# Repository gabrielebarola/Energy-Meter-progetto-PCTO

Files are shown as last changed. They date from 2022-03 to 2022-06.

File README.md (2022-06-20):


<!-- PROJECT LOGO -->
<br />
<div align="center">
  <a href="https://github.com/gabrielebarola/Energy-Meter-progetto-PCTO/">
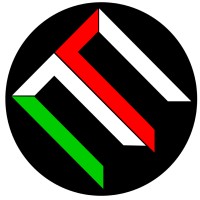
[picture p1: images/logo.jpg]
    
  </a>

<h3 align="center">Energy meter</h3>

  <p align="center">
    Progetto per il percorso di PCTO 2021/2022
  </p>
</div>

<!-- ABOUT THE PROJECT -->
## Il progetto

<div align="center">
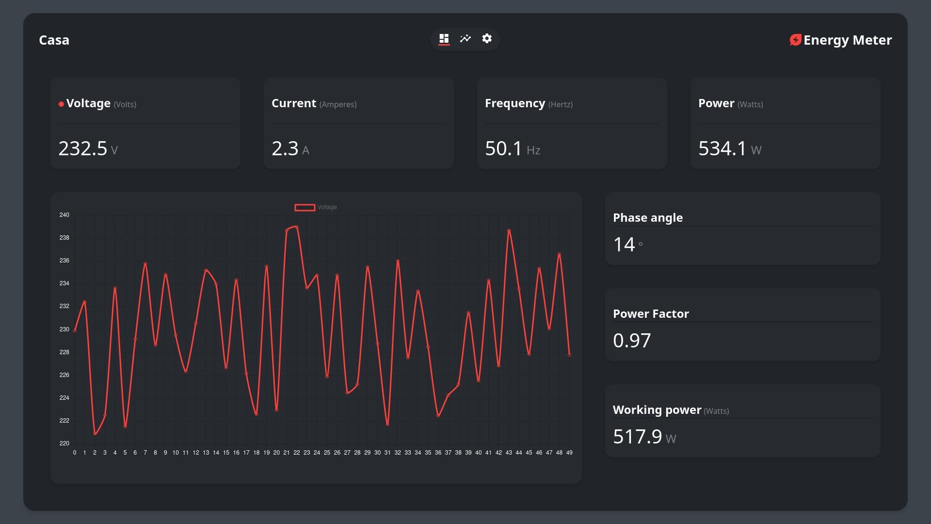
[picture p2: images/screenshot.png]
Dashboard
  
</div>

Cercando di collegare l'attività del PCTO con le tematiche trattate in educazione civica durante l'anno, ho deciso di sviluppare un sistema in grado di monitorare i parametri necessari per mostrare all'utente in modo semplice lo stato dell'impianto elettrico della propria abitazione e lo storico dei consumi, con l'obiettivo di incentivare un utilizzo più consapevole dell'energia elettrica.

Il progetto unisce in unico pacchetto tutte le funzionalità di seguito riportate e analizzate nello specifico successivamente.

* MISURA DELLE PRINCIPALI GRANDEZZE DI UN IMPIANTO ELETTRICO
* CALCOLO DELLA POTENZA E DEL FATTORE DI POTENZA
* VISUALIZZAZIONE DEI DATI IN TEMPO REALE
* GRAFICI INTERATTIVI

## Altre tecnologie e software utilizzati

* [MicroPython](https://micropython.org/)
* [Kicad](https://www.kicad.org/)
* [VSCode](https://code.visualstudio.com/)
* [MicroWebSrv2](https://github.com/jczic/MicroWebSrv2)
* [Charts.js](https://github.com/chartjs/Chart.js)

## Presentazione per l'esame di stato

<div>
  <a href="https://docs.google.com/presentation/d/1edAisyT30yDkEmbcdj5mdHnbcW9ENNGRGbsqXM53MuE/edit?usp=sharing">
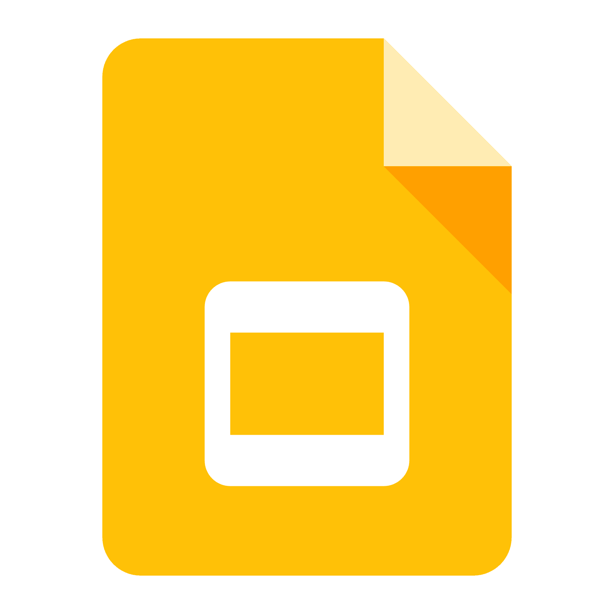
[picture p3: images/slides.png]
Clicca per vedere la presentazione
    
  </a>
  Premere sul logo per vedere la presentazione
</div>

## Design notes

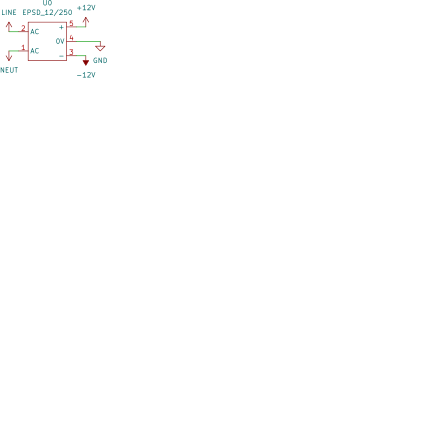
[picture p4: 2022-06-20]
kicad/tensione/al.png

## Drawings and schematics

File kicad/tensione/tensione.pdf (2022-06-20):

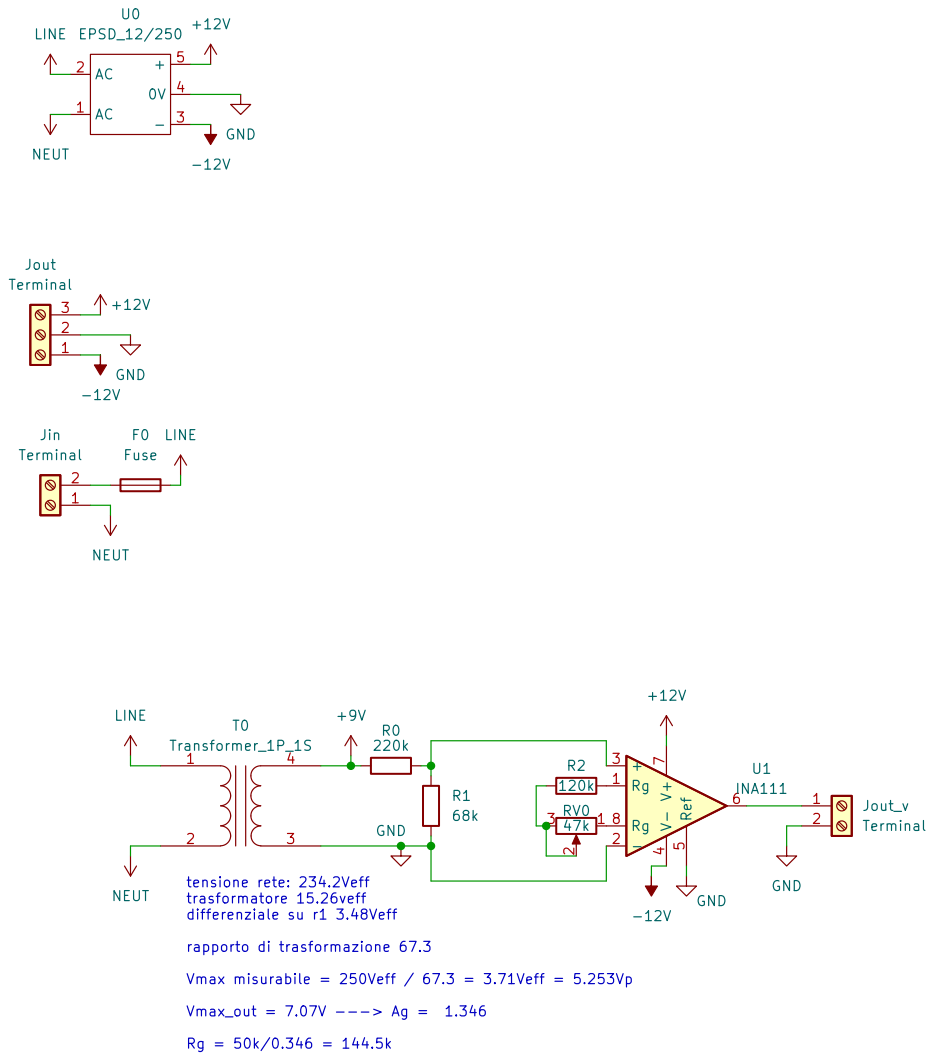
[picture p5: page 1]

tensione rete: 234.2Veff
trasformatore 15.26veff differenziale su r1 3.48Veff rapporto di trasformazione 67.3

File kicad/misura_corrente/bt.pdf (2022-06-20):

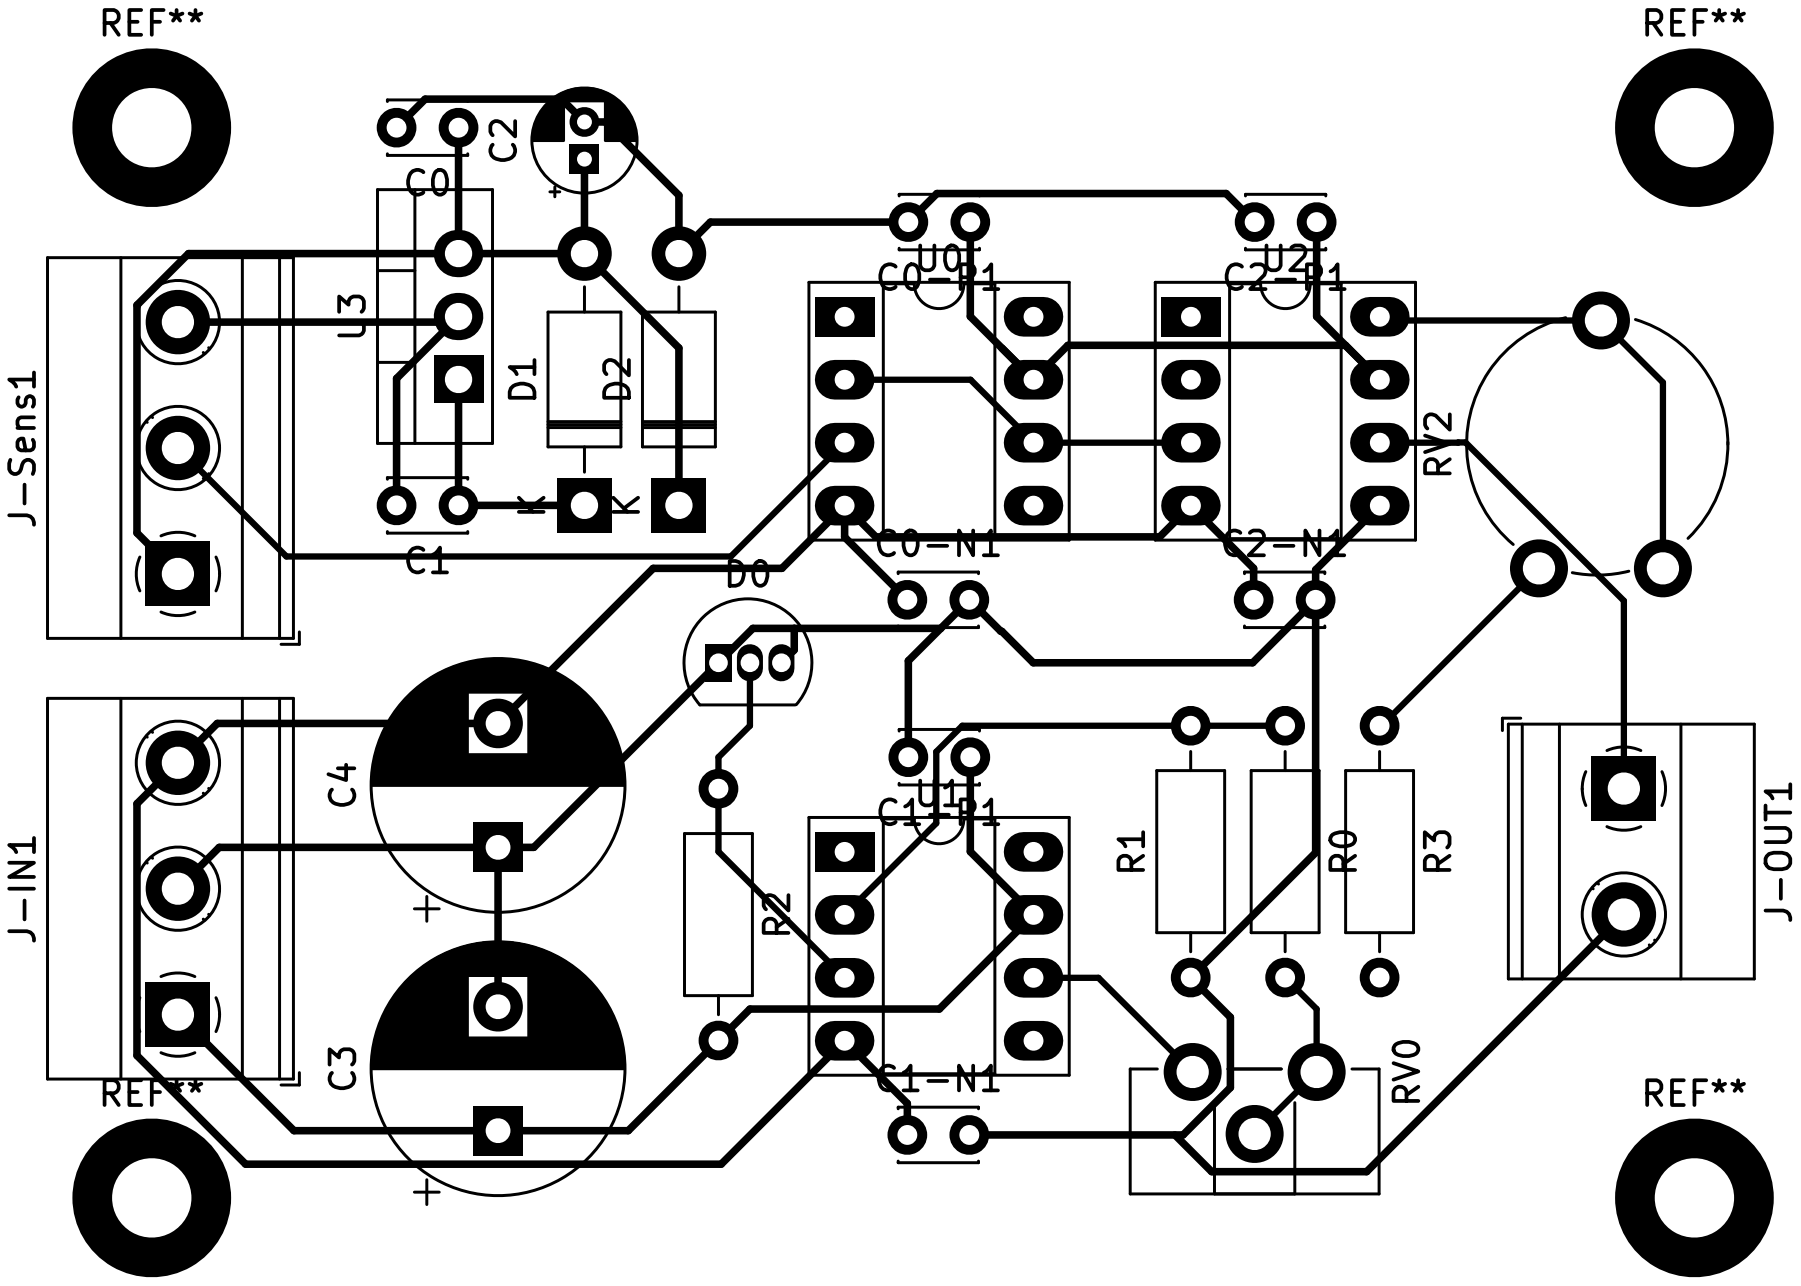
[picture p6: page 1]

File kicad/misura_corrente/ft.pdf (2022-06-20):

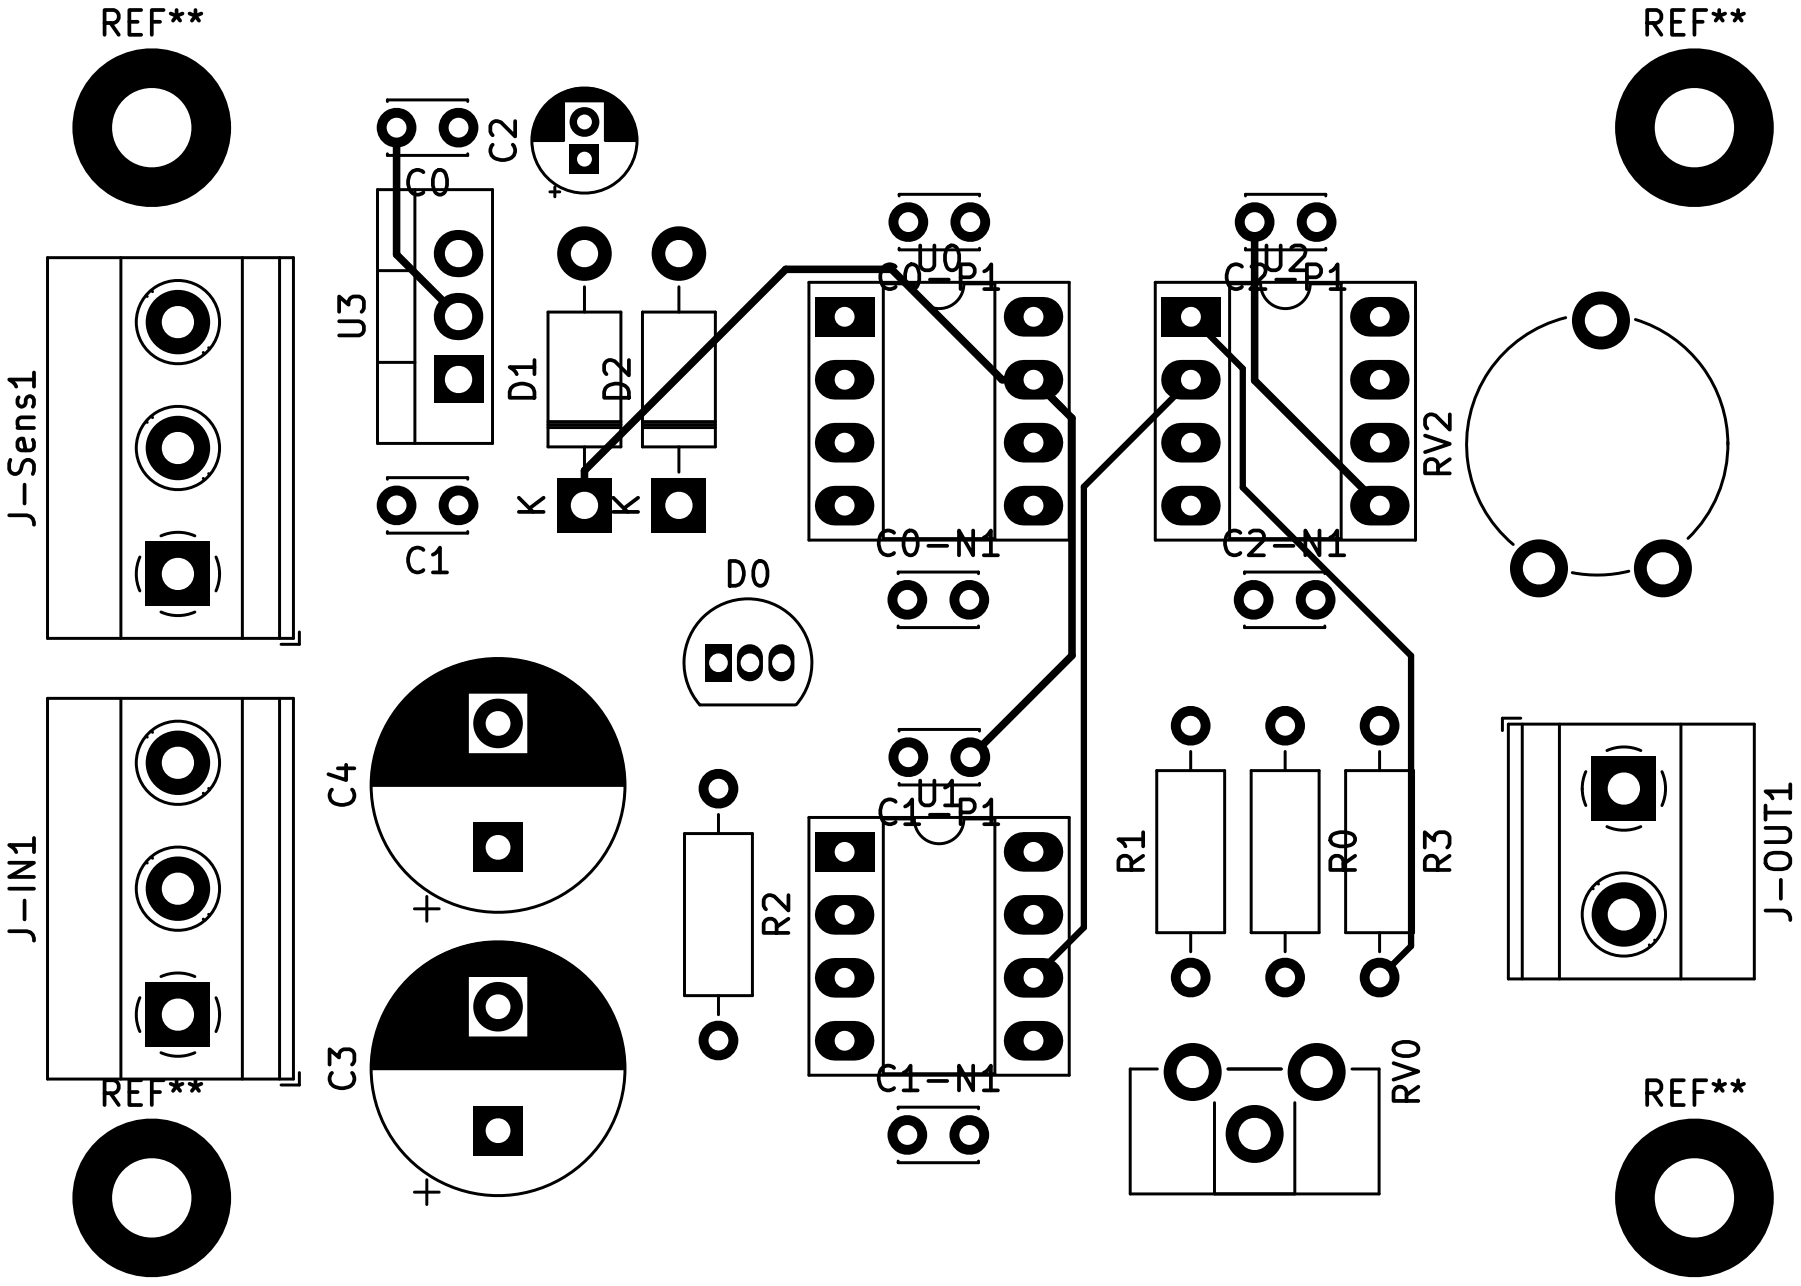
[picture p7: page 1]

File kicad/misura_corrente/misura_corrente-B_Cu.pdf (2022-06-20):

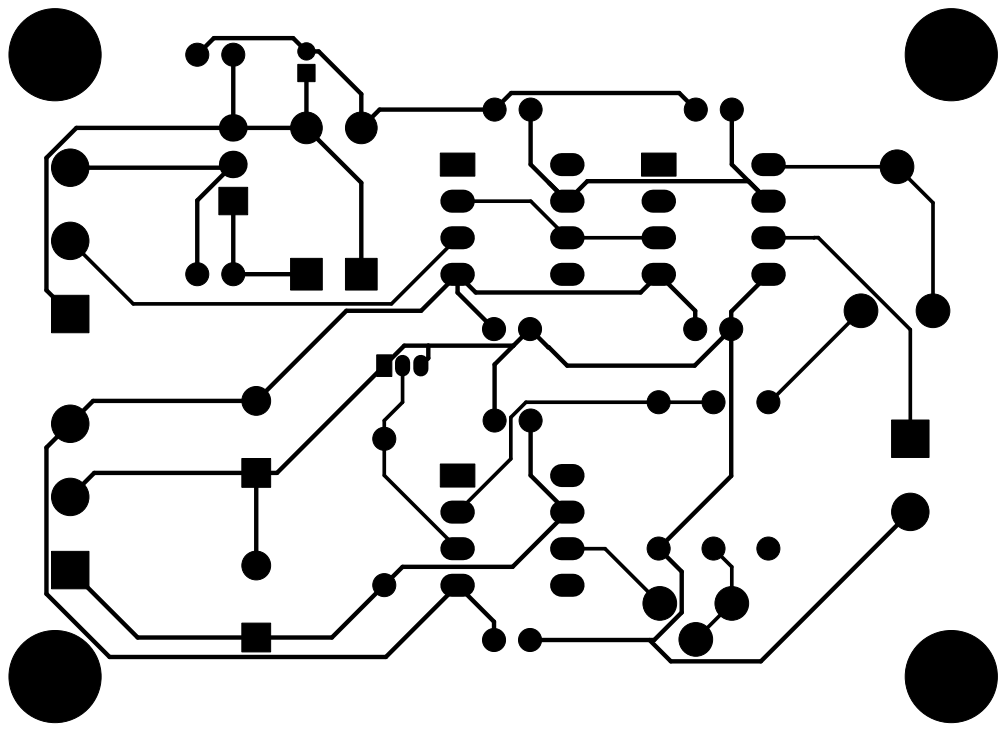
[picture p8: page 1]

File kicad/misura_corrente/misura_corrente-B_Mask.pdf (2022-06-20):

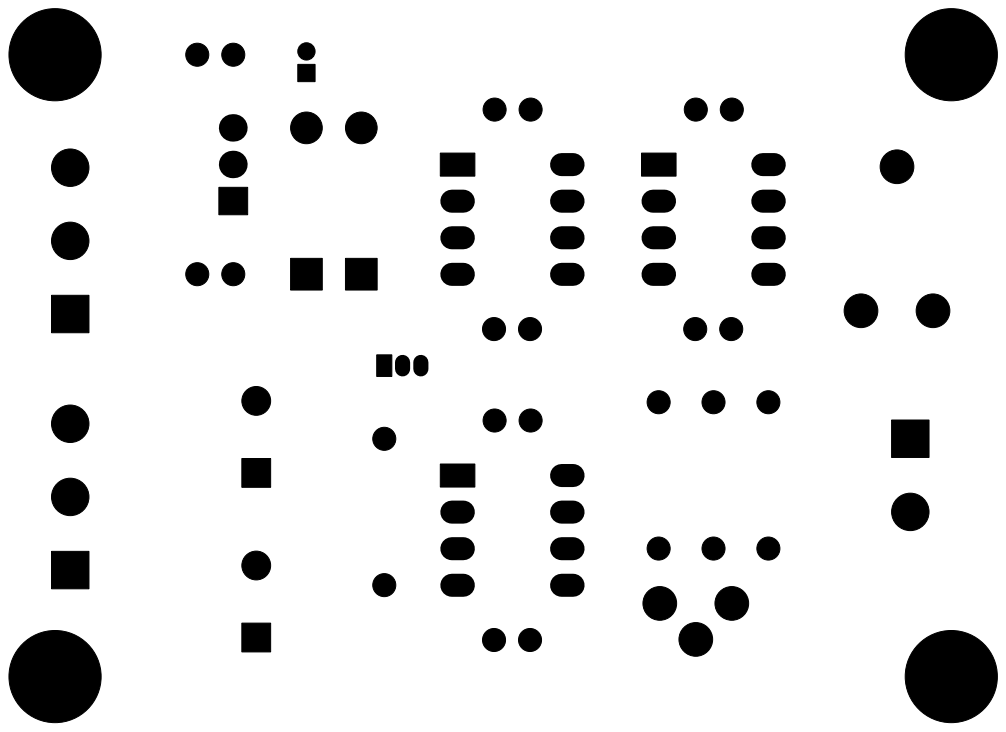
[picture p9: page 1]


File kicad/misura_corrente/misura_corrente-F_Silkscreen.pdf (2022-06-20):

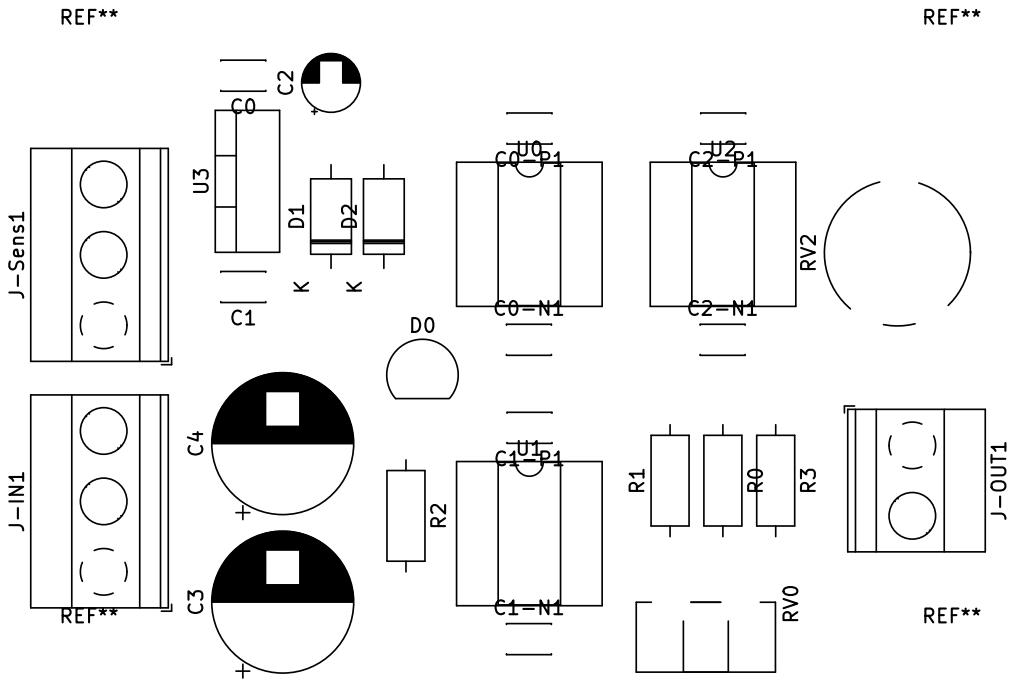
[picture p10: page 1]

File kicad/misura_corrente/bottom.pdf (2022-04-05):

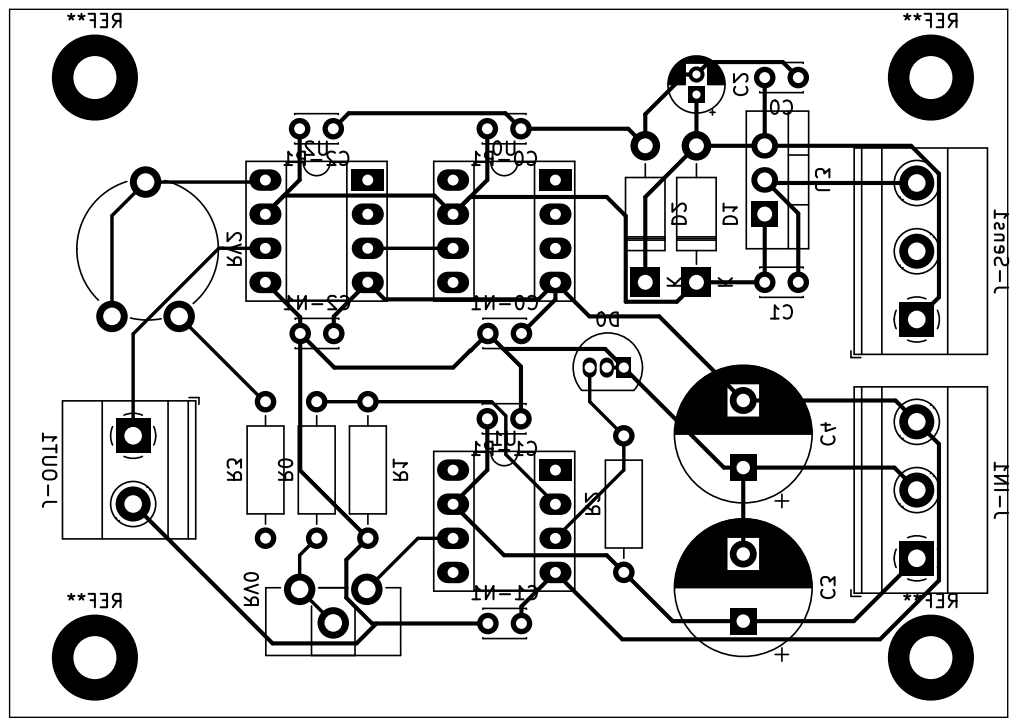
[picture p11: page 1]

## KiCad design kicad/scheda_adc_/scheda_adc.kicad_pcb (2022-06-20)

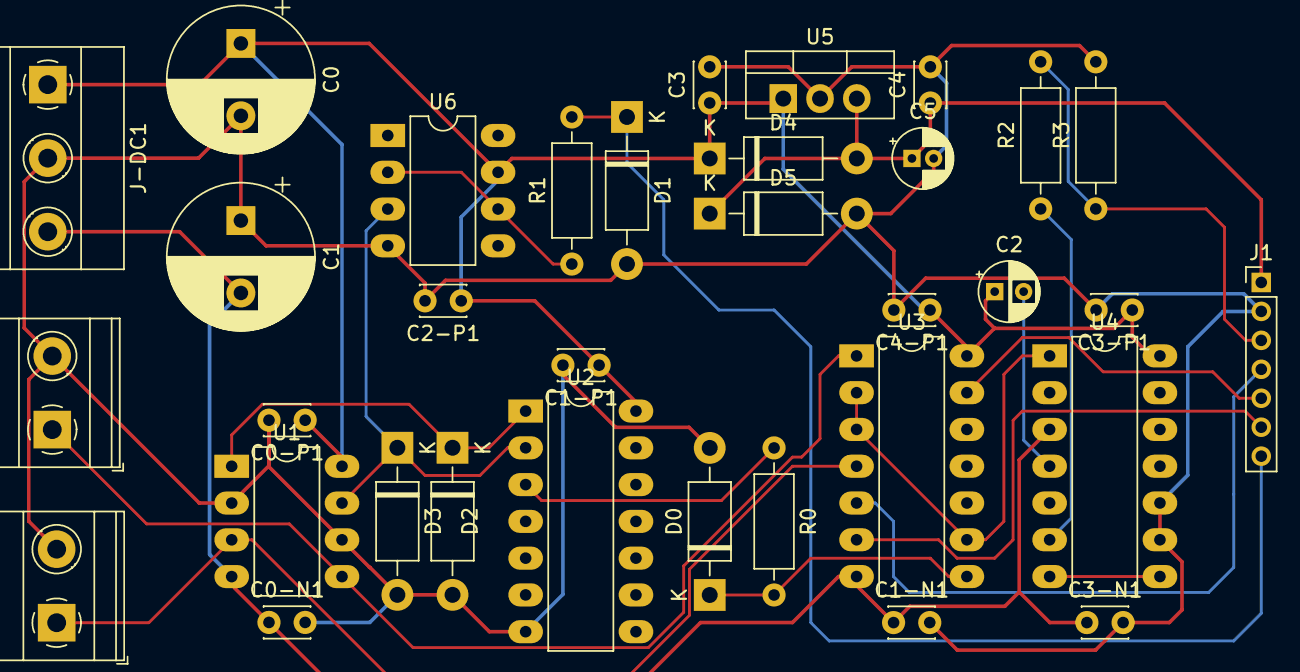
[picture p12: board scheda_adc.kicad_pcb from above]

Board: 2 copper layers, 34 parts (0 on the bottom side), 20 nets.

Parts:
C0, C1: 330uF; CP_Radial_D10.0mm_P5.00mm
C0-N1, C0-P1, C1-N1, C1-P1, C2-P1, C3-N1, C3-P1, C4, C4-P1: 100nF; C_Disc_D3.0mm_W2.0mm_P2.50mm
C2: 4,7uF; CP_Radial_D4.0mm_P2.00mm
C3: 330nF; C_Disc_D3.0mm_W2.0mm_P2.50mm
C5: 47uF; CP_Radial_D4.0mm_P1.50mm
D0: 5V; D_DO-41_SOD81_P10.16mm_Horizontal
D1: 3,3V; D_DO-41_SOD81_P10.16mm_Horizontal
D2, D3: 1N4007; D_DO-41_SOD81_P10.16mm_Horizontal
D4, D5: 1N4001; D_DO-41_SOD81_P10.16mm_Horizontal
J1: Conn_01x07_Male; PinHeader_1x07_P2.00mm_Vertical
J-DC1: j; TerminalBlock_Phoenix_MKDS-1,5-3-5.08_1x03_P5.08mm_Horizont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
J-I1: Screw_Terminal_01x02; TerminalBlock_Phoenix_MKDS-1,5-2-5.08_1x02_P5.08mm_Horizont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
J-V1: Screw_Terminal_01x02; TerminalBlock_Phoenix_MKDS-1,5-2-5.08_1x02_P5.08mm_Horizont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
R0, R1: 1.5K; R_Axial_DIN0207_L6.3mm_D2.5mm_P10.16mm_Horizontal
R2, R3: 15k; R_Axial_DIN0207_L6.3mm_D2.5mm_P10.16mm_Horizontal
U1: LM358; DIP-8_W7.62mm_LongPads
U2: 4070; DIP-14_W7.62mm_LongPads
U3: 4066; DIP-14_W7.62mm_LongPads
U4: AD536A; DIP-14_W7.62mm_LongPads
U5: L7805; TO-220-3_Vertical
U6: CA3140; DIP-8_W7.62mm_LongPads

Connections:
+5V: C4.1, C5.1, D4.2 (A), D5.1 (K), J1.1, U5.3 (OUT)
+12V: C0.1, C0-P1.1, C1-P1.1, C2.1, C2-P1.1, C3.1, C3-P1.1, C4-P1.1, D4.1 (K), J-DC1.1, U1.8 (V+), U2.14 (VDD), U3.14 (VDD), U4.14 (Vs+), U5.1 (IN), U6.7 (V+)
-12V: C0-N1.1, C1.2, C1-N1.1, C3-N1.1, J-DC1.3, U1.4 (V-), U3.7 (VSS), U4.3 (Vs-)
ADC_IN: J1.3, R2.2, R3.1
EN_I: J1.4, U3.5
EN_P: J1.6, U3.6
EN_V: J1.5, U3.13
FREQUENCY: D1.1 (K), J1.7, R1.2
GNDA: C0.2, C0-N1.2, C0-P1.2, C1.1, C1-N1.2, C1-P1.2, C2-P1.2, C3.2, C3-N1.2, C3-P1.2, C4.2, C4-P1.2, C5.2, D0.2 (A), D1.2 (A), D2.2 (A), D3.2 (A), D5.2 (A), J1.2, J-DC1.2, J-I1.2, J-V1.2, R3.2, U1.2 (-), U1.6 (-), U2.7 (VSS), U4.9 (Rl), U4.10 (COM), U5.2 (GND), U6.4 (V-)
unnamed: C2.2, U4.4 (Cav)
unnamed: D2.1 (K), U1.1, U2.1
unnamed: D3.1 (K), U1.7, U2.2, U6.3 (+)
unnamed: R0.1, U2.3
unnamed: R1.1, U6.2 (-), U6.6
unnamed: U3.2, U3.3, U3.9, U4.1 (Vin)
unnamed: R2.1, U4.6 (Vout)
unnamed: U4.7 (Buf_in), U4.8 (Iout)
PHASE: D0.1 (K), R0.2, U3.8
V_CORRENTE: J-I1.1, U1.3 (+), U3.4
V_TENSIONE: J-V1.1, U1.5 (+), U3.1

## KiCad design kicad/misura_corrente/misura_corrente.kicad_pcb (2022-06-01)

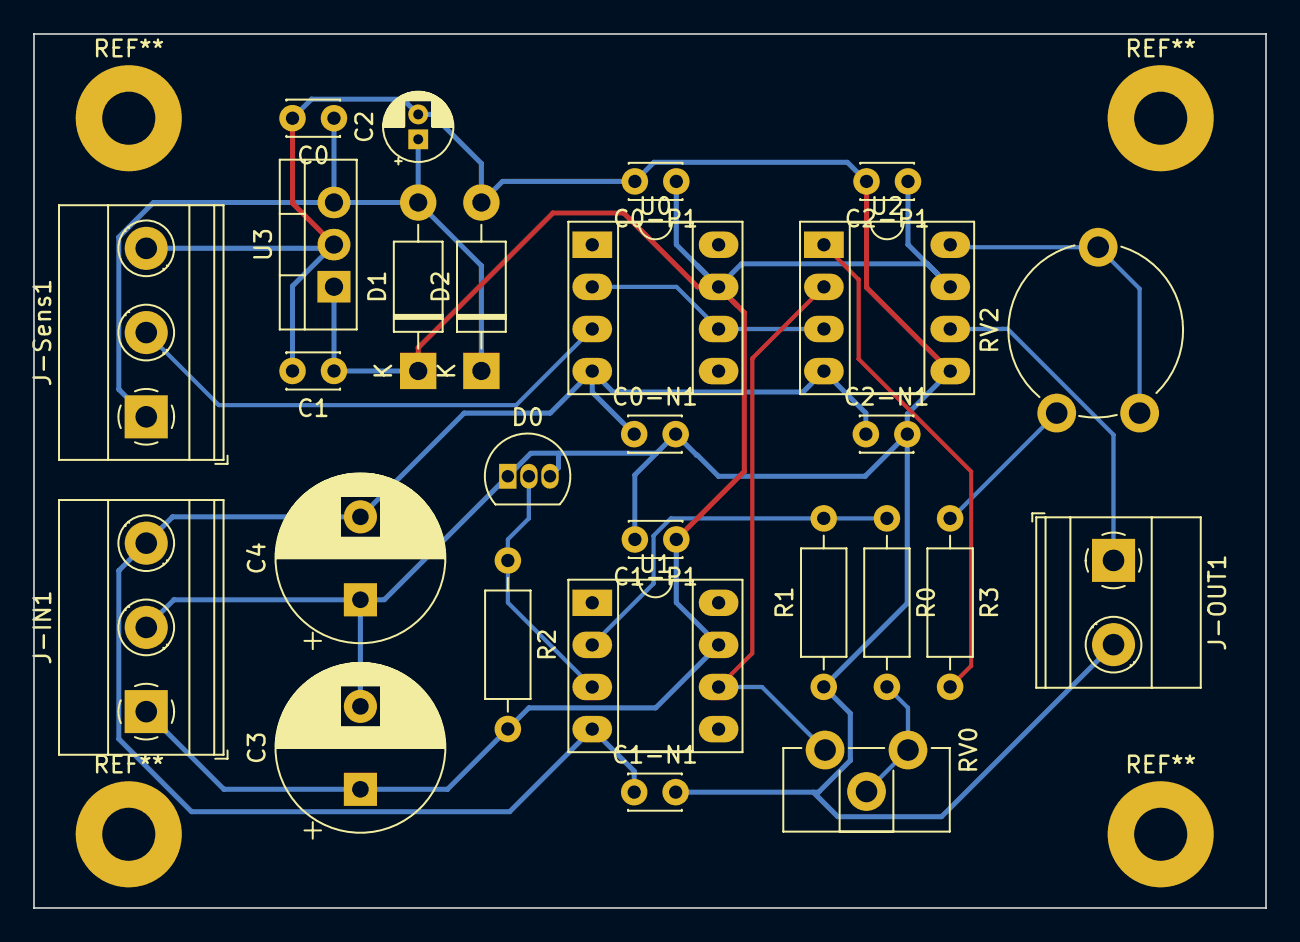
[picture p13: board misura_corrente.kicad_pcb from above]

Board: 2 copper layers, 74.3 x 52.7 mm, 27 parts (0 on the bottom side), 14 nets.

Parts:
C0, C0-N1, C0-P1, C1-N1, C1-P1, C2-N1, C2-P1: 100nF; C_Disc_D3.0mm_W2.0mm_P2.50mm
C1: 330nF; C_Disc_D3.0mm_W2.0mm_P2.50mm
C2: 47uF; CP_Radial_D4.0mm_P1.50mm
C3, C4: 330uF; CP_Radial_D10.0mm_P5.00mm
D0: LM336z25; TO-92L_Inline
D1, D2: 1N4001; D_DO-41_SOD81_P10.16mm_Horizontal
J-IN1: j; TerminalBlock_Phoenix_MKDS-1,5-3-5.08_1x03_P5.08mm_Horizont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
J-OUT1: Screw_Terminal_01x02; TerminalBlock_Phoenix_MKDS-1,5-2-5.08_1x02_P5.08mm_Horizont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
J-Sens1: CSLA2CD; TerminalBlock_Phoenix_MKDS-1,5-3-5.08_1x03_P5.08mm_Horizont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
R0: 5.6k; R_Axial_DIN0207_L6.3mm_D2.5mm_P10.16mm_Horizontal
R1: 10k; R_Axial_DIN0207_L6.3mm_D2.5mm_P10.16mm_Horizontal
R2: 3.6k; R_Axial_DIN0207_L6.3mm_D2.5mm_P10.16mm_Horizontal
R3: 8.2k; R_Axial_DIN0207_L6.3mm_D2.5mm_P10.16mm_Horizontal
RV0: 2.2k; Potentiometer_ACP_CA9-H2,5_Horizontal
RV2: 2.2k; Potentiometer_Piher_PT-10-V10_Vertical
U0, U1: CA3140; DIP-8_W7.62mm_Socket_LongPads
U2: INA111; DIP-8_W7.62mm_Socket_LongPads
U3: L7808; TO-220-3_Vertical

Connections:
+8V: C0.1, C2.1, D1.2 (A), D2.1 (K), J-Sens1.1, U3.3 (OUT)
+12V: C0-P1.1, C1.1, C1-P1.1, C2-P1.1, C3.1, D1.1 (K), J-IN1.1, R2.2, U0.7 (V+), U1.7 (V+), U2.7 (V+), U3.1 (IN)
-12V: C0-N1.1, C1-N1.1, C2-N1.1, C4.2, J-IN1.3, U0.4 (V-), U1.4 (V-), U2.4 (V-)
GNDA: C0.2, C0-N1.2, C0-P1.2, C1.2, C1-N1.2, C1-P1.2, C2.2, C2-N1.2, C2-P1.2, C3.2, C4.1, D0.1 (Adj), D0.3 (V-), D2.2 (A), J-IN1.2, J-OUT1.2, J-Sens1.3, R1.1, U2.5 (Ref), U3.2 (GND)
I-SENS: U0.2 (-), U0.6, U2.3 (+)
I-SIN-OUT: J-OUT1.1, U2.6
unnamed: D0.2 (V+), R2.1, U1.3 (+)
unnamed: J-Sens1.2, U0.3 (+)
unnamed: R0.1, R1.2, U1.2 (-)
unnamed: R0.2, RV0.1, RV0.2
unnamed: R3.1, RV2.3
unnamed: R3.2, U2.1 (Rg)
unnamed: RV2.1, RV2.2, U2.8 (Rg)
VREF: RV0.3, U1.6, U2.2 (-)

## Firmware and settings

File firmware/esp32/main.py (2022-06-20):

from MicroWebSrv2 import MicroWebSrv2
from time import sleep_ms, time
from machine import Timer, RTC
from micropython import const
from src.database import Database
from src.logger import Logger
import json, gc

_mins = const(5)
_secs = const(5 * 60)
_diff = const(946684800)

db = Database("prova1db")
logger = Logger(freq=15, adc=32, en_i=19, en_v=21, en_p=22)
connected_sockets = []


def update_sockets():
    for socket in connected_sockets:
        socket.SendTextMessage(
            json.dumps({"type": "measures", "content": logger.readings})
        )


def OnWebSocketTextMessage(websocket, msg):
    if "chart-from-to" in msg:
        splitted = msg.split(":")
        from_timestamp = int(splitted[1]) - _diff
        to_timestamp = int(splitted[2]) - _diff
        websocket.SendTextMessage(json.dumps({"type": "chart-init"}))

        for i in range((to_timestamp - from_timestamp) // _secs):
            to_get = from_timestamp + ((i + 1) * _secs)
            data = db.get(str(to_get).encode())

            websocket.SendTextMessage(
                json.dumps(
                    {
                        "type": "chart-append",
                        "content": {"timestamp": to_get + _diff, "measures": data},
                    }
                )
            )

        websocket.SendTextMessage(json.dumps({"type": "chart-init-stop"}))


def OnWebSocketClosed(websocket):
    connected_sockets.remove(websocket)


def OnWebSocketAccepted(server, websocket):
    connected_sockets.append(websocket)
    websocket.OnTextMessage = OnWebSocketTextMessage
    websocket.OnClosed = OnWebSocketClosed


def log_data():
    t = time()
    db.log(t, logger.readings)

    for socket in connected_sockets:
        socket.SendTextMessage(
            json.dumps(
                {
                    "type": "chart-add",
                    "content": {
                        "timestamp": t + _diff,
                        "measures": logger.readings,
                    },
                }
            )
        )


def main():

    rtc = RTC()
    print(rtc.datetime())

    to_init = True  # init the timer only when time is multiple of _mins

    server = MicroWebSrv2()

    sockets = server.LoadModule("WebSockets")
    sockets.OnWebSocketAccepted = OnWebSocketAccepted

    server.NotFoundURL = "/"
    server.SetEmbeddedConfig()

    server.StartManaged()

    logging_timer = Timer(0)

    try:
        while True:
            logger.read()
            update_sockets()

            # evaluates if minutes is multiple of 15 to start the timer
            if to_init and not rtc.datetime()[5] % _mins:
                log_data()

                logging_timer.init(
                    period=(_mins * 60000),
                    callback=lambda t: log_data(),
                )
                to_init = False

            gc.collect()

    except KeyboardInterrupt:
        logging_timer.deinit()
        server.Stop()
        db.close()


if __name__ == "__main__":
    main()

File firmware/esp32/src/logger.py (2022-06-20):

from machine import Pin, ADC, time_pulse_us
from micropython import const
import time


_ref = const(2450000)
_ref_v = const(250)
_ref_i = const(25)

_offset = const(142000)  # misurato su ingresso adc collegato a massa 142000


class Logger:
    def __init__(self, freq, adc, en_i, en_v, en_p):

        self.freq = Pin(freq, Pin.IN)
        self.adc = ADC(Pin(adc, Pin.IN), atten=ADC.ATTN_11DB)

        self.en_i = Pin(en_i, Pin.OUT)
        self.en_v = Pin(en_v, Pin.OUT)
        self.en_p = Pin(en_p, Pin.OUT)

        self.readings = [0.0, 0.0, 0.0, 0.0]
        self._reset_en()

    def _reset_en(self):
        self.en_i.off()
        self.en_v.off()
        self.en_p.off()

    def read_freq(self):
        _, half = time_pulse_us(self.freq, 1), time_pulse_us(self.freq, 1)
        period = 2 * half
        freq = 1e6 / (period)
        return round(freq, 1)

    def _read_samples(self, samples):
        l = []
        time.sleep_ms(600)  # da datasheet ad536

        for i in range(samples):

            time.sleep_us(15)
            val = self.adc.read_uv()
            l.append(val)

        return (sum(l) / len(l)) - _offset

    def read_v(self, samples=50):
        self._reset_en()
        self.en_v.on()
        mean = self._read_samples(samples)

        return (mean / _ref) * _ref_v

    def read_i(self, samples=50):
        self._reset_en()
        self.en_i.on()
        mean = self._read_samples(samples)

        return (mean / _ref) * _ref_i

    def read_p(self, samples=50):
        self._reset_en()
        self.en_p.on()
        mean = self._read_samples(samples)  # valore efficace

        dc = (mean / _ref) ** 2  # duty cycle

        phase = dc * 180

        return int(phase)

    def read(self):
        self.readings[0] = self.read_v()
        self.readings[1] = self.read_i()
        self.readings[2] = self.read_freq()
        self.readings[3] = self.read_p()

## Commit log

2022-03-08 schema elettrico fino a ina111
    [misura_corrente.kicad_pcb, misura_corrente.kicad_sch]
2022-03-21 aggiunte footprint
    [misura_corrente.kicad_sch]
2022-03-22 fatto pcb per millefori
    [misura_corrente.kicad_pcb, misura_corrente.kicad_sch]
2022-03-22 stampa pdf
    [misura_corrente.kicad_pcb]
2022-04-05 configurazione vscode e documento
    [misura_corrente.kicad_pcb, misura_corrente.kicad_sch]
2022-04-13 creata pagina di prova
2022-04-20 fine pagina di prova
2022-05-16 iniziata schda acquisizione
    [scheda_adc.kicad_pcb, scheda_adc.kicad_sch, tensione.kicad_pcb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]
2022-05-16 schema elettrico misura fase
    [scheda_adc.kicad_sch]
2022-05-16 inizio modifica socket e passaggio a request
2022-06-01 continuazione documentazione corrente (todo 3d)
    [scheda_adc.kicad_pcb, scheda_adc.kicad_sch]
2022-06-20 fine progetto principale
    [misura_corrente.kicad_pcb, scheda_adc.kicad_pcb, scheda_adc.kicad_sch]
